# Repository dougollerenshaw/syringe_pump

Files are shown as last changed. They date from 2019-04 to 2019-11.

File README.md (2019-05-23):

# syringe pump CAD model and control code
source files to build and run a syringe pump

syringe pump model is built in freecad

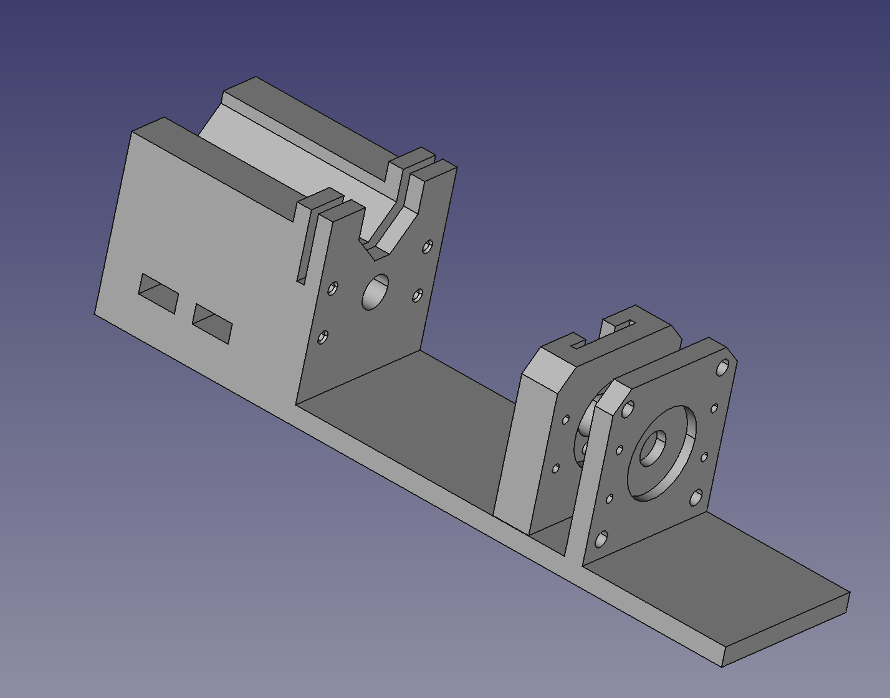
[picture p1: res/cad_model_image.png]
CAD model


Designed to use a Nema 17 stepper motor with an A4988 microstepping driver

Python code communicates with an arduino via USB serial using the PyFirmata package. Arduino controls the stepper driver with digital outputs.

Arduino should have `StandardFirmata` code uploaded (from the arduino IDE: `File > Examples > Firmata > StandardFirmata`)

Arduino wiring and microstepping logic follow the conventions described here:
https://howtomechatronics.com/tutorials/arduino/how-to-control-stepper-motor-with-a4988-driver-and-arduino/

## For remote operation
Pyro4 is used for remote communication

Usage:

On raspberry pi, both a Pyro4 nameserver and the stepper_server must be running

To run nameserver
```
$ conda activate syringe_pump
$ python -m Pyro4.naming -n <IP OF PI>
```

To run stepper_server:
```
$ conda activate syringe_pump
$ python stepper_server.py
```

On remote computer:
```
$ conda activate syringe_pump
```

Then, at a python prompt:
```
>> import Pyro4
>> s = Pyro4.Proxy("PYRONAME:stepper.server")
>> s.calibrate('1ml') #or '5ml'
```

To test remote connection:
```
>> s._pyroBind() # should return True
>> s.toggle_builtin_led() # should toggle the builtin arduino LED
```

To dispense 10 uL:
```
>> s.dispense(10)
```

To retract 100 uL
```
>> s.retract(100)
```

Pyro also allows connections through html.
On raspberry pi:
```
$ python -m Pyro4.utils.httpgateway -H <IP OF PI> -e stepper.server
```

From a browser:

to deliver a 10 ul reward:
```
http://<IP OF PI>:8080/pyro/stepper.server/deliver_reward?volume=10
```

to check the step count:
```
http://<IP OF PI>:8080/pyro/stepper.server/step_count
```

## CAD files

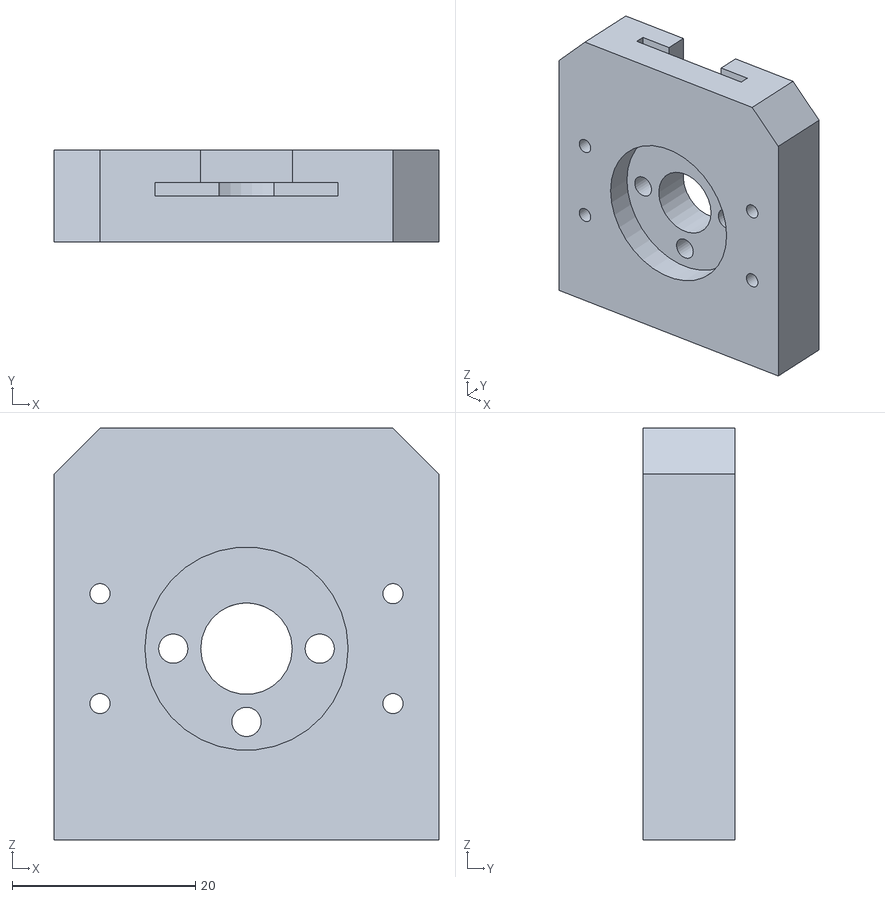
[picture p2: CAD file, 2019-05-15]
CAD_files/syringe_pump_carriage.stl
42.0 x 10.0 x 45.0

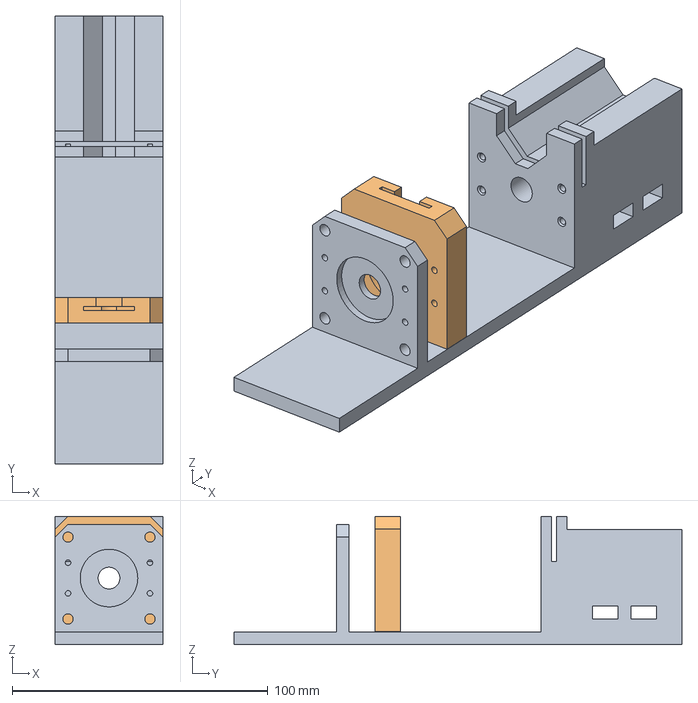
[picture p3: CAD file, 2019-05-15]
CAD_files/syringe_pump_v2.FCStd
42.0 x 175.0 x 50.1 mm

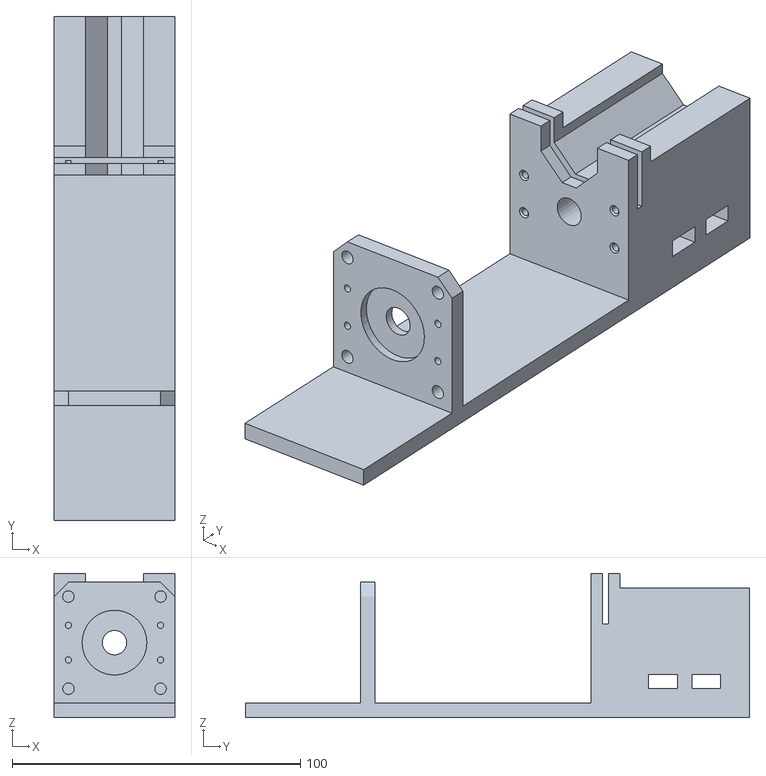
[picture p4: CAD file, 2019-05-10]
CAD_files/syringe_pump_body.stl
42.0 x 175.0 x 50.0

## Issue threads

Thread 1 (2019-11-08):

self.delay for arduino mode

danieljdenman, 2019-11-08:
hi Doug! finally got around to setting this up in the lab.
mostly working in one afternoon. motor isn't stepping but maybe the controller is bad or my power supply the motor is bad.
one bug, line 62 of stepper.py
`self.delay = 0.00025 # delay between ttl pulses when stepping`
should move one indent up, so that it can be used in both arduino and rpi mode.

dougollerenshaw, 2019-11-11:
Nice catch. Fixed in commit c6ed76d317a003e49091f6f981f07f83354bde7d

Closed 2019-11-11.

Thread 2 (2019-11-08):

mc1,2,3 with ArduinoMega

danieljdenman, 2019-11-08:
also, i used
`self.arduino = ArduinoMega(port)`
at line 46, since i apparently bought ArduinoMega (and of course imported ArduinoMega from pyfirmata).
are the mc1, mc2,and mc3 values in the config likely to be different?

danieljdenman, 2019-11-11:
specified the pins in `configuration_values` in config.py. working! closed.

dougollerenshaw, 2019-11-11:
Great! Does this mean that the stepping issue you mentioned in issue #1 is solved? Is it fully working now?

dougollerenshaw, 2019-11-11:
Just in case, I've noticed that the stepper driver is somewhat fragile. If you make a mistake in wiring, it's easy to burn out an internal component, which makes troubleshooting tough. It's sometimes worth plugging a new driver into your breadboard if you've triple-checked the wiring and the stepper still won't step.

danieljdenman, 2019-11-11:
yes, working now. i remembered that you had burned a driver out, so i had cycled through a few in troubleshooting! but i don't think the driver was the issue (i made a mistake in the wiring and RESET and SLEEP weren't tied to each other. doing that finally got the driver producing its output).

i haven't calibrated yet so don't know if it *fully* working, but commands to dispense and retract seem to work, and the travel is proportional to the amount.

in addition to reward delivery, i'm still hoping to print a version that holds a hamilton syringe, to use it for nL - uL injections. will update if i get this done.

dougollerenshaw, 2019-11-11:
Good news. Let me know how it goes. I'd appreciate PR submissions if you make any useful code changes. The readme is in particular need of help if you have time to add any notes you make during the setup process.

Closed 2019-11-11.

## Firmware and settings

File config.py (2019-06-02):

import socket
import subprocess

configuration_values = {
    'servername':'stepper.server',
    'syringe':'3ml',
    'mode':'rpi',
    'disable_pin':21,
    'dir_pin':5,
    'step_pin':6,
    'mc1':20,
    'mc2':19,
    'mc3':16,
}

class Config(object):
    def __init__(self):
        self.hostname = self.get_hostname()
        self.ip = self.get_ip()
        for key in configuration_values:
            setattr(self, key, configuration_values[key])

    def get_hostname(self):
        return socket.gethostname()

    def get_ip(self):
        hostname = self.get_hostname()
        ip = subprocess.check_output(['hostname', '-I'])
        return ip.decode("utf-8").split()[0]

if __name__ == '__main__':
    config = Config()
    print(config.servername)
    print(config.ip)

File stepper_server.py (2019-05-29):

from stepper import Stepper
from config import Config
from pyfirmata import Arduino, util
from gpiozero import DigitalOutputDevice
import Pyro4

Pyro4.config.REQUIRE_EXPOSE = False


# NOTE: must have nameserver running on same device
# for example: `python -m Pyro4.naming -n 192.168.0.46 -p 1234`


@Pyro4.expose
class StepperServer(Stepper):
    def __init__(self, syringe='3ml', mode='rpi', port=None):
        Stepper.__init__(self, port=port, syringe=syringe)
        # self.arduino = Arduino(port)
        print('running stepper server')
        print('usb port = {}'.format(port))
        print('syringe = {}'.format(syringe))

    @Pyro4.oneway
    def deliver_reward(self, volume):
        '''
        a one-way (non-blocking) method for delivering a reward
        '''
        self.dispense(volume)

    @Pyro4.expose
    def get_step_count(self):
        return self.step_count

    @Pyro4.expose
    def set_step_count(self,value):
        self.step_count = value

    @Pyro4.expose
    def get_volume_dispensed(self):
        return self.volume_dispensed

    @Pyro4.expose
    def set_volume_dispensed(self,value):
        self.volume_dispensed = 0

    @Pyro4.expose
    def get_max_limit(self):
        return self.max_limit

    @Pyro4.expose
    def get_min_limit(self):
        return self.min_limit


if __name__ == '__main__':

    config = Config()
    server = StepperServer(
        syringe=config.syringe,
        mode=config.mode,
    )

    daemon = Pyro4.Daemon(config.ip)                # make a Pyro daemon
    ns = Pyro4.locateNS()                  # find the name server
    print("nameserver = {}".format(ns))
    # register the stepper server as a Pyro object
    uri = daemon.register(server)
    # register the object with a name in the name server
    ns.register(config.servername, uri)

    # print("The daemon runs on port: {}".format(daemon.port))
    print("The object's uri is: {}".format(uri))

    print("Ready.")
    # start the event loop of the server to wait for calls
    daemon.requestLoop()

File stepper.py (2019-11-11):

# from pyfirmata import Arduino, util
from gpiozero import DigitalOutputDevice
import random
from config import Config
import time


class Stepper(object):
    def __init__(self, syringe='5ml', mode='rpi', disable_when_inactive=True, port=None,):
        self.mode = mode
        config = Config()
        if self.mode == 'arduino':
            self.arduino = Arduino(port)
            self.disable_pin = config.disable_pin
            self.dir_pin = config.dir_pin
            self.step_pin = config.set_pin
            self.mc1 = config.mc1
            self.mc2 = config.mc2
            self.mc3 = config.mc3
        elif self.mode == 'rpi':
            self.disable_pin = DigitalOutputDevice(config.disable_pin)
            self.dir_pin = DigitalOutputDevice(config.dir_pin)
            self.step_pin = DigitalOutputDevice(config.step_pin)
            self.mc1 = DigitalOutputDevice(config.mc1)
            self.mc2 = DigitalOutputDevice(config.mc2)
            self.mc3 = DigitalOutputDevice(config.mc3)
            self.pin8 = DigitalOutputDevice(4)
            
        self.delay = 0.00025 # delay between ttl pulses when stepping


        # should we turn off the motor between commands?
        self.disable_when_inactive = disable_when_inactive

        # the following are specific to a NEMA17 stepper with a T8 leadscrew
        self.steps_per_rotation = 200
        self.mm_per_rotation = 8

        self.step_count = 0
        self.volume_dispensed = 0
        self.dispense_limit = None # set as minimum step number to avoid bottoming out
        self.retract_limit = None  # set as maximum step number to keep from pulling plunger from syringe
        self._direction_multiplier = 0

        self.set_mm_per_ml(syringe, calibrate_steps=False)

        self._pin13 = 0

        self.stepsize = "sixteenth"
        self.set_stepsize(self.stepsize)

        self.direction = "cw"
        self.set_direction(self.direction)

        if self.disable_when_inactive:
            self.set_pin(self.disable_pin, 1)
        else:
            self.set_pin(self.disable_pin, 0)

    def calibrate(self, syringe):
        self.set_mm_per_ml(syringe, calibrate_steps=True)

    def set_mm_per_ml(self, syringe, calibrate_steps=True):
        mm_per_ml = {
            '5ml': 44./5,
            '3ml': 51.7/3,
            '1ml': 57.
        }

        self.mm_per_ml = mm_per_ml[syringe.lower()]
        print('configuring for a {} syringe with {} mm of travel per mL'.format(
            syringe, self.mm_per_ml))
        if calibrate_steps:
            self.set_steps_per_ul()

    def set_steps_per_ul(self):
        self.ul_per_step = 1000 / \
            (self.mm_per_ml/self.mm_per_rotation *
             self.steps_per_rotation/self._step_deci)

    def set_stepsize(self, stepsize):
        step_def = {
            'full': [0, 0, 0],
            'half': [1, 0, 0],
            'quarter': [1, 0, 1],
            'eighth': [1, 1, 0],
            'sixteenth': [1, 1, 1]
        }
        step_deci = {
            'full': 1.,
            'half': 1./2,
            'quarter': 1./4,
            'eighth': 1./8,
            'sixteenth': 1./16
        }
        for i, pin in enumerate([self.mc1, self.mc2, self.mc3]):
            self.set_pin(pin, step_def[stepsize][i])
        self._stepsize = stepsize
        self._step_deci = step_deci[stepsize]
        self.set_steps_per_ul()

    def toggle_builtin_led(self):
        print('current state is {}, setting to {}'.format(
            self._pin13, abs(self._pin13 - 1)))
        self.set_pin(13, abs(self._pin13 - 1))
        self._pin13 = abs(self._pin13 - 1)

    def set_pin(self, pin_to_set, state):
        if self.mode == 'arduino':
            self.arduino.digital[pin_to_set].write(state)
        elif self.mode == 'rpi':
            pin_to_set.value = state

    def set_direction(self, direction):

        if direction.lower() == 'cw' or direction.lower() == 'retract':
            self.set_pin(self.dir_pin, 0)
            self._direction_multiplier = -1
        elif direction.lower() == 'ccw' or direction.lower() == 'dispense':
            self.set_pin(self.dir_pin, 1)
            self._direction_multiplier = 1
        self._direction = direction
        return direction

    def dispense(self, volume):
        steps = float(volume)/self.ul_per_step
        # the following line will deal with fractional steps by probabalistically rounding
        #  up or down (e.g. 1.75 will be 2 75% of the time and 1 25% of the time)
        #  this will prevent systematic biases in the amount of fluid delivered
        steps = int(steps) + int(random.random() < (steps % 1))
        self.volume_dispensed += float(steps)*float(self.ul_per_step)
        print('delivering {} ul in {} steps for a total volume of {}'.format(volume, steps, self.volume_dispensed))
        self.rotate(steps, direction='dispense', delay=self.delay)

    def retract(self, volume=1000):
        steps = round(float(volume)/self.ul_per_step)
        self.volume_dispensed -= float(steps)*float(self.ul_per_step)
        print('retracting {} ul in {} steps for a total volume of {}'.format(volume, steps, self.volume_dispensed))
        self.rotate(steps, direction='retract', delay=self.delay)

    def rotate(self, steps, direction=None, delay=0.000):
        # make sure direction and stepsize are set
        if direction is not None:
            self.direction = self.set_direction(direction)
        if self.stepsize != self._stepsize:
            self.set_stepsize(self.stepsize)
        if self.direction != self._direction:
            self.set_direction(self.direction)

        # cast steps as int
        steps = int(steps)

        # enable stepper
        if self.disable_when_inactive:
            self.set_pin(self.disable_pin, 0)
            time.sleep(0.001) #1 ms delay to make sure the motor is engaged before trying to turn

        # toggle step pin in loop
        for i in range(steps):
            self.step_count += self._direction_multiplier
            self.set_pin(self.step_pin, 0)
            self.set_pin(self.step_pin, 1)
            time.sleep(delay)

        # disable stepper (otherwise it makes a high pitch whine while it waits)
        if self.disable_when_inactive:
            time.sleep(0.001) #1 ms delay to make sure the motor is done turning before disengaging
            self.set_pin(self.disable_pin, 1)
        print('done stepping, current step count = {}'.format(self.step_count))
        time.sleep(delay)

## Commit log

2019-04-17 stepper control code - initial commit
2019-04-17 Syringe pump model - initial commit
    [syringe_pump_5ml_v2.FCStd]
2019-04-17 cad model image
2019-04-25 add stepper server - receive communication with pyro
2019-04-25 linux file type changes (no content changes)
    [syringe_pump_5ml_v2.FCStd]
2019-04-25 make syringe configurable
2019-04-25 add print statements in server
2019-05-01 add calibration method
2019-05-03 retract at current stepsize
2019-05-09 add 3ml calibration
2019-05-09 updates to pump gui
2019-05-10 updates to pump_gui
2019-05-10 update to pump_gui
2019-05-10 Added STL files, moved to CAD_files folder
    [syringe_pump_body.stl, syringe_pump_carriage.stl, syringe_pump_v2.FCStd]
2019-05-10 pump_gui changes
2019-05-14 keep track of step location
2019-05-14 more mods to keep track of step count
2019-05-15 simplify pump gui
2019-05-15 updating CAD file to increase height of carriage
    [syringe_pump_carriage.stl, syringe_pump_v2.FCStd]
2019-05-22 direction pin typo
2019-05-23 modifying stepper_server
2019-05-23 stepper server uses config to get IP address (instead of hardcoding!)
2019-05-29 local updates to pump_gui.py
2019-05-29 make 3ml default
2019-05-29 adding code to track total volume
2019-06-02 moved pin numbers to config
2019-06-02 switch dir and step pin numbers
2019-11-11 set delay for both arduino and rpi modes
